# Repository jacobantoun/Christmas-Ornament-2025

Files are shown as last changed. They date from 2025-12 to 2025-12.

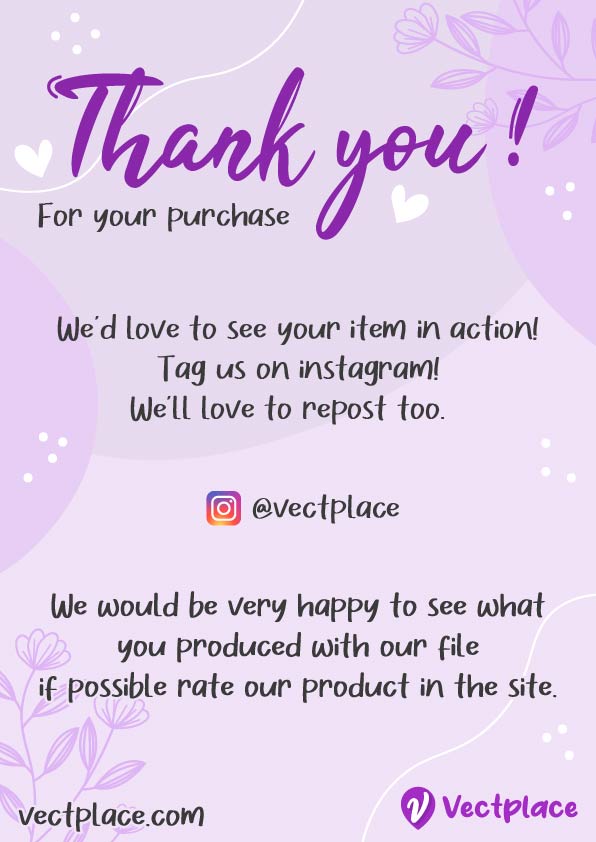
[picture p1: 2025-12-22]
KiCad/ChristmasOrnament25/Vectplace/Read-me.jpg

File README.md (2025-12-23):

# Jacob's Somewhat Yearly Christmas Ornament PCB

## About this Ornament
Each year I try to design a Christmas themed PCB and often get carried away trying to make them fancier than they need to be. This year I just stuck with creating a basic PCB with minimial functionality that's hard to mess up. I had a bunch of 3mm LEDs laying around and a couple sleeves of the Atmel (Microchip) ATTiny816 laying around waiting to be used.
The ornament makes use of the AVRs built in sleep functionality. I have ornaments from a few years ago that still have the original battery because of how good the sleep mode is.
## Build Pictures





## How to use
Press the button and the LEDs will do stuffs
## Programming
Source code can be found in the repo. The PCB contains a 2x3 pinheader for use with the Atmel ICE. The header is correct for the included 10 pin adapter cable. The PCB is also labeled with the appropriate UPDI pins.
## Building the Ornaments
Remind me next year to let JLCPCB assemble these... and to not use through-hole components. I wanted to save money by soldering the thru-hole components myself, but bending, placing, soldering, and snipping all the leads took forever. There is something satisfying about assembling these all myself though.

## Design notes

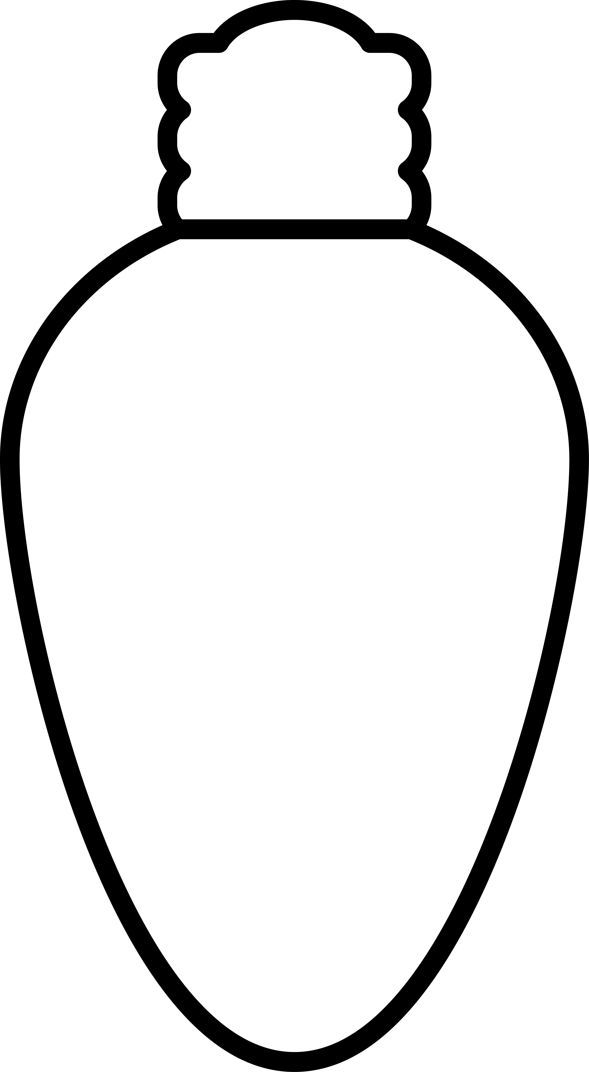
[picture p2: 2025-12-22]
KiCad/ChristmasOrnament25/Vectplace/PNG/PNG.png

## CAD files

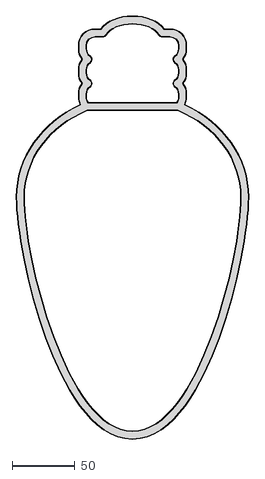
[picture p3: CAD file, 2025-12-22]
KiCad/ChristmasOrnament25/Vectplace/DXF/VP1490 Christmas Light Bulb Outline SVG.dxf
184.5 x 336.0

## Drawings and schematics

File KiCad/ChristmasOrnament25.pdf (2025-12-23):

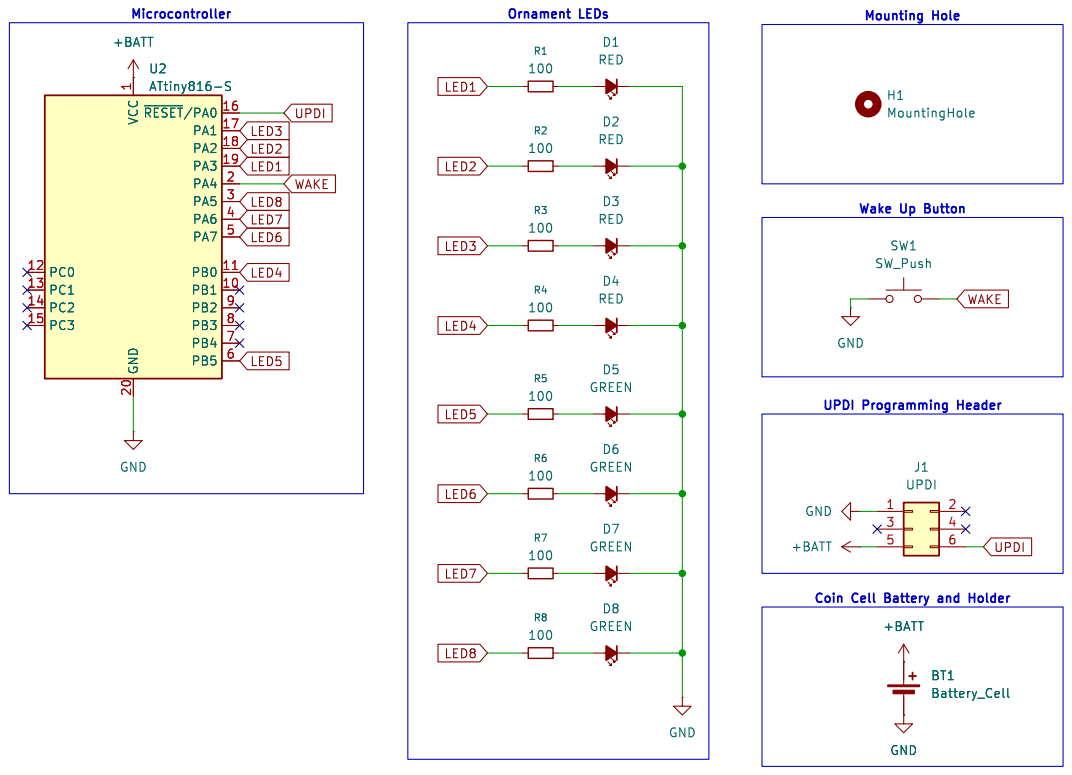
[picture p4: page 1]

Id: 1/1 Title: Christmas Ornament 2025

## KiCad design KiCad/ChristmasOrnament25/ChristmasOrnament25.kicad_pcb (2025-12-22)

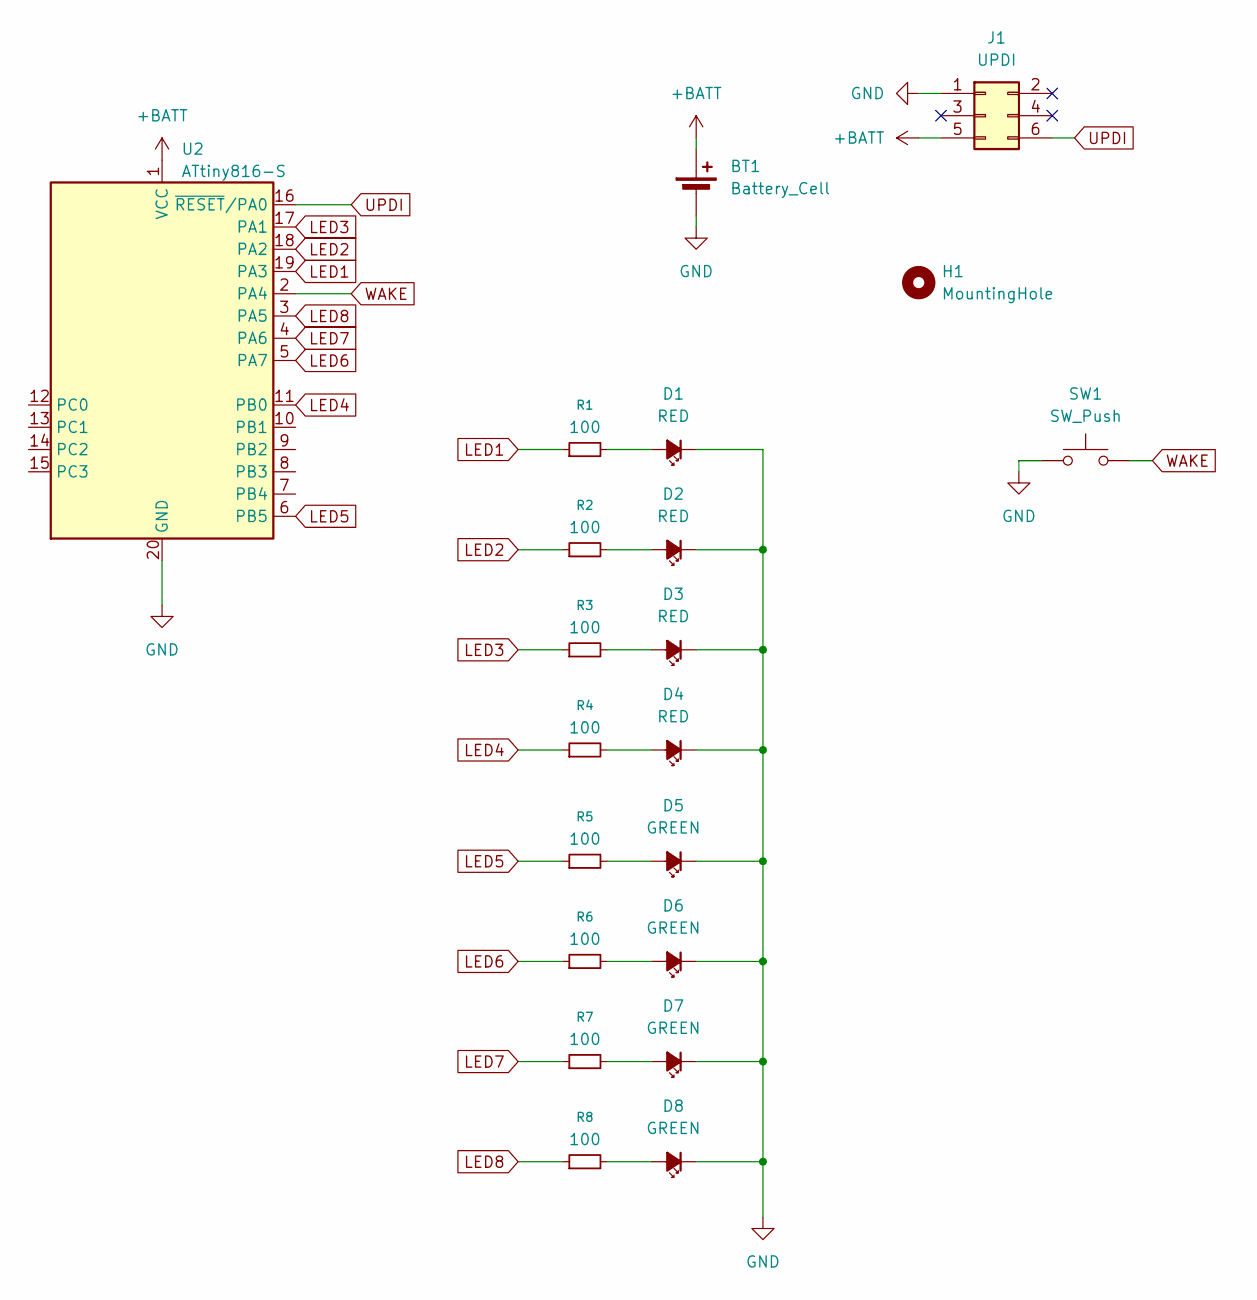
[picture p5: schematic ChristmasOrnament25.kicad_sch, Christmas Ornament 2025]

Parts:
BT1: Battery_Cell; BatteryHolder_Keystone_3002_1x2032; Manufacturer PN BAT-HLD-001-THM
D1, D2, D3, D4: RED; LED_D3.0mm
D5, D6, D7, D8: GREEN; LED_D3.0mm
H1: MountingHole; MountingHole_2.5mm
J1: UPDI; PinHeader_2x03_P2.54mm_Vertical; Manufacturer PN PR20203VBDN
R1, R2, R3, R4, R5, R6, R7, R8: 100; R_Axial_DIN0207_L6.3mm_D2.5mm_P7.62mm_Horizontal
SW1: SW_Push; SW_TH_Tactile_Omron_B3F-100x; Manufacturer PN B3F-1000
U2: ATtiny816-S; SOIC-20W_7.5x12.8mm_P1.27mm

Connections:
+BATT: BT1.1 (+), J1.5, U2.1 (VCC)
GND: BT1.2 (-), D1.1 (K), D2.1 (K), D3.1 (K), D4.1 (K), D5.1 (K), D6.1 (K), D7.1 (K), D8.1 (K), J1.1, SW1.1, U2.20 (GND)
LED1: R1.1, U2.19 (PA3)
LED2: R2.1, U2.18 (PA2)
LED3: R3.1, U2.17 (PA1)
LED4: R4.1, U2.11 (PB0)
LED5: R5.1, U2.6 (PB5)
LED6: R6.1, U2.5 (PA7)
LED7: R7.1, U2.4 (PA6)
LED8: R8.1, U2.3 (PA5)
unnamed: D1.2 (A), R1.2
unnamed: D2.2 (A), R2.2
unnamed: D3.2 (A), R3.2
unnamed: D4.2 (A), R4.2
unnamed: D5.2 (A), R5.2
unnamed: D6.2 (A), R6.2
unnamed: D7.2 (A), R7.2
unnamed: D8.2 (A), R8.2
UPDI: J1.6, U2.16 (~RESET/PA0)
WAKE: SW1.2, U2.2 (PA4)

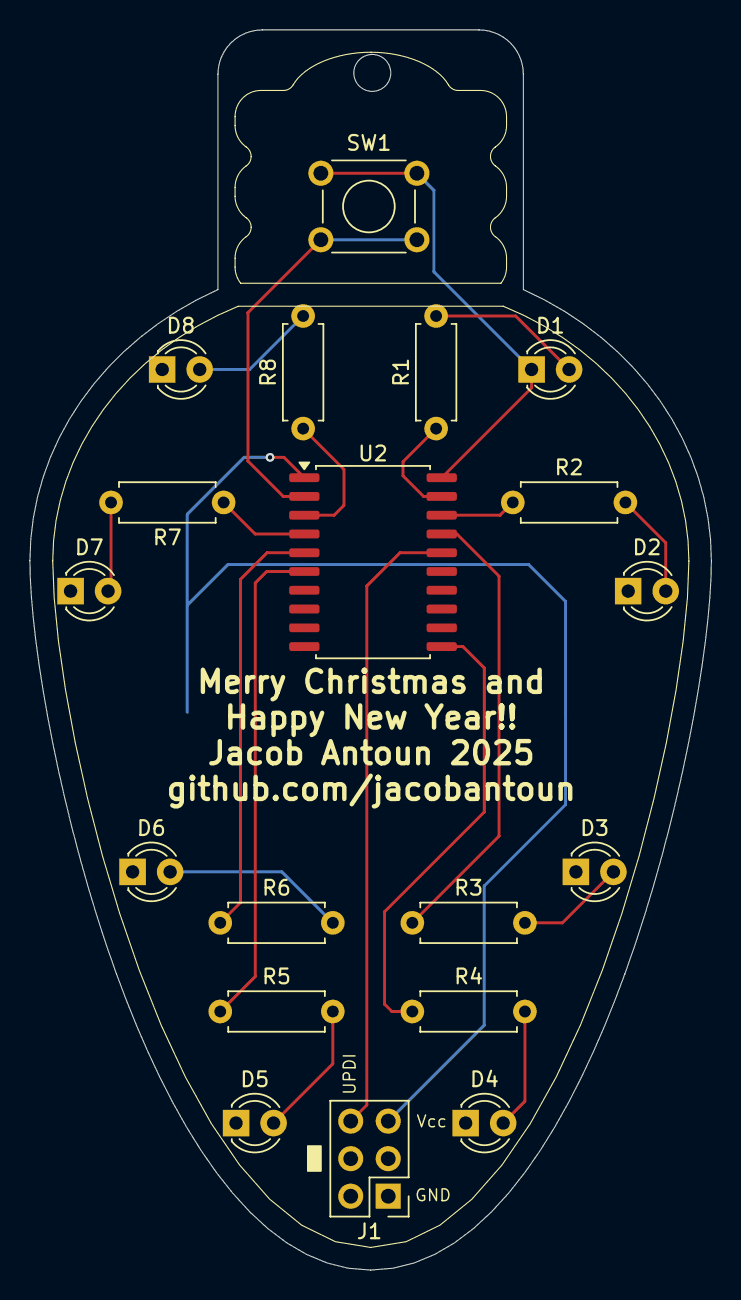
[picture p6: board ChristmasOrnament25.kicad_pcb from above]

Board: 2 copper layers, 46.1 x 83.9 mm, 21 parts (1 on the bottom side), 20 nets.

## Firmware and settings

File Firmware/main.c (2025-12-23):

#include <avr/io.h>
#include <util/delay.h>
#include <avr/interrupt.h>
#include <avr/sleep.h>
#include <stdlib.h>  // For rand()

#define CHASER_DELAY_TIME 500
#define TWINKLE_DELAY_TIME 100

// Function prototypes
void init_leds(void);
void led_on(uint8_t led_number);
void led_off(uint8_t led_number);
void all_leds_off(void);
void single_led_chaser_cw(uint8_t number_of_cycles);
void single_led_chaser_ccw(uint8_t number_of_cycles);
void double_led_chaser(uint8_t number_of_cycles);
void twinkling_stars(uint8_t cycles, uint16_t base_delay_ms);
void delay_millis(uint16_t ms);


// Function to blink the LED connected to PA5 five times
void blink_five_times(void) {
	for (uint8_t i = 0; i < 5; i++) {
		PORTA.OUTSET = (1 << 5);  
		_delay_ms(500);           
		PORTA.OUTCLR = (1 << 5);  
		_delay_ms(500);           
	}
}

// Interrupt Service Routine for PORTA
ISR(PORTA_PORT_vect) {
	PORTA.INTFLAGS = (1 << 4);  // Clear the interrupt flag for PA4
}

int main(void) {
	
    // Set LEDs as output
	init_leds();
    
	// Switch on PA4. Set as input, pull up enable, interrupt
	PORTA.DIRCLR = (1 << 4);
	PORTA.PIN4CTRL = PORT_PULLUPEN_bm | PORT_ISC_BOTHEDGES_gc;  // Enable pull-up and both-edges interrupt
	
	// Set the sleep mode to Power-Down for low power consumption
	set_sleep_mode(SLEEP_MODE_PWR_DOWN);
	
	// Perform the initial blinking sequence
	blink_five_times();
	
	// Main loop: Sleep, wake on interrupt, check pin state, blink if pressed, repeat
	while (1) {
		sleep_enable();      // Enable sleep mode
		sei();               // Enable global interrupts
		sleep_cpu();         // Enter sleep mode (wakes on interrupt)
		sleep_disable();     // Disable sleep mode after wake-up
		
		_delay_ms(10);       // Brief debounce delay
		
		// Check if the button is pressed
		if (!(PORTA.IN & (1 << 4))) {
			single_led_chaser_cw(2);
			_delay_ms(1000);
			single_led_chaser_ccw(2);
			all_leds_off();
			_delay_ms(500);
			twinkling_stars(15, 1000);
			
		}
	}
	
	return 0;
}

// Function to initialize all LED pins as outputs
void init_leds(void) 
{
	// Configure PORTA pins: PA3, PA2, PA1, PA7, PA6, PA5 as outputs
	PORTA.DIRSET = (1 << 3) | (1 << 2) | (1 << 1) | (1 << 7) | (1 << 6) | (1 << 5);
	
	// Configure PORTB pins: PB0, PB5 as outputs
	PORTB.DIRSET = (1 << 0) | (1 << 5);
}

// This functions turns a specific LED (D1 - D8) ON
void led_on(uint8_t led_number)
{
	if(led_number < 1 || led_number > 8)
	{
		return;
	}
	switch(led_number)
	{
		case 1: PORTA.OUTSET = (1 << 3); break;
		case 2: PORTA.OUTSET = (1 << 2); break;
		case 3: PORTA.OUTSET = (1 << 1); break;
		case 4: PORTB.OUTSET = (1 << 0); break;
		case 5: PORTB.OUTSET = (1 << 5); break;
		case 6: PORTA.OUTSET = (1 << 7); break;
		case 7: PORTA.OUTSET = (1 << 6); break;
		case 8: PORTA.OUTSET = (1 << 5); break;
	}
}

// This functions turns a specific LED (D1 - D8) OFF
void led_off(uint8_t led_number)
{
	if(led_number < 1 || led_number > 8)
	{
		return;
	}
	switch(led_number)
	{
		case 1: PORTA.OUTCLR = (1 << 3); break;
		case 2: PORTA.OUTCLR = (1 << 2); break;
		case 3: PORTA.OUTCLR = (1 << 1); break;
		case 4: PORTB.OUTCLR = (1 << 0); break;
		case 5: PORTB.OUTCLR = (1 << 5); break;
		case 6: PORTA.OUTCLR = (1 << 7); break;
		case 7: PORTA.OUTCLR = (1 << 6); break;
		case 8: PORTA.OUTCLR = (1 << 5); break;
	}
}

// Turns off all LEDs at once
void all_leds_off(void)
{
	PORTA.OUTCLR = (1 << 3) | (1 << 2) | (1 << 1) | (1 << 7) | (1 << 6) | (1 << 5);
	PORTB.OUTCLR = (1 << 0) | (1 << 5);
}

// Creates a small led "chaser". One LED is on and circling around the ornament clockwise
void single_led_chaser_cw(uint8_t number_of_cycles)
{
	for(uint8_t c = 0; c < number_of_cycles; c++)
	{
		for(uint8_t i = 1; i <= 8; i++)
		{
			all_leds_off();
			led_on(i);
			_delay_ms(CHASER_DELAY_TIME);
		}
	}
	all_leds_off();
}

// Function for single-LED chaser in a ring pattern (reverse direction)
void single_led_chaser_ccw(uint8_t number_of_cycles) 
{
	for (uint8_t c = 0; c < number_of_cycles; c++) {
		for (uint8_t i = 8; i >= 1; i--) {
			all_leds_off();       
			led_on(i);            
			_delay_ms(CHASER_DELAY_TIME);  
		}
	}
	all_leds_off();  
}

// Same as single_led_chaser() but with two LEDs instead of one.
void double_led_chaser(uint8_t number_of_cycles)
{
	for (uint8_t c = 0; c < number_of_cycles; c++) {
		for (uint8_t i = 1; i <= 8; i++) {
			all_leds_off();      
			led_on(i);           
			uint8_t next = (i % 8) + 1;  
			led_on(next);         
			_delay_ms(CHASER_DELAY_TIME);  
		}
	}
	all_leds_off();  // Ensure all off at end
}

// Revised twinkling stars function with variable delay support
void twinkling_stars(uint8_t cycles, uint16_t base_delay_ms) 
{
	srand(0xABCD);  // Seed random number generator 
	all_leds_off();
	for (uint8_t c = 0; c < cycles; c++) {
		uint8_t led = (rand() % 8) + 1;  // Select random LED from 1 to 8
		led_on(led);
		delay_millis(base_delay_ms + (rand() % 200));  // Variable delay
		led_off(led);
		_delay_ms(50);
	}
	all_leds_off();
}

void delay_millis(uint16_t ms)
{
	while(ms--)
	{
		_delay_ms(1);
	}
}

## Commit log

2025-12-22 Added KiCad files
    [ChristmasOrnament25-B_Cu.gbr, ChristmasOrnament25-B_Mask.gbr, ChristmasOrnament25-B_Paste.gbr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]
2025-12-23 Create ChristmasOrnament25.pdf Schematic
2025-12-23 Add image to README for Christmas Ornament PCB
    Added an image to the README for better visual representation.
